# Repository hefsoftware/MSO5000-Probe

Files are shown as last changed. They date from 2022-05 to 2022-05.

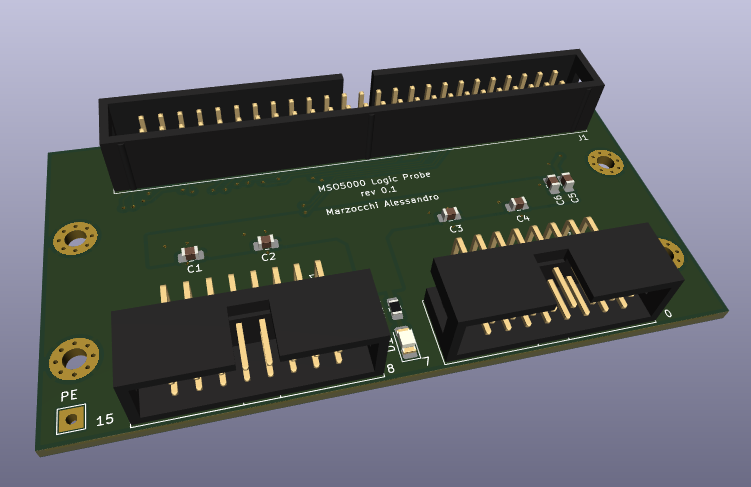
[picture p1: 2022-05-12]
docs/3dView-Top.png

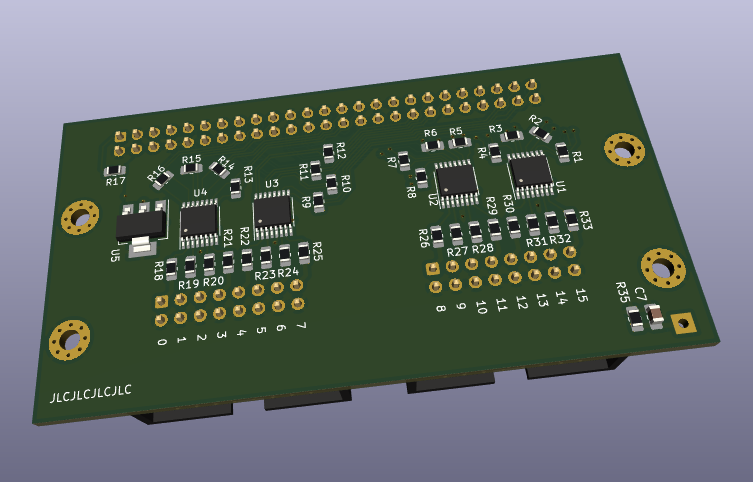
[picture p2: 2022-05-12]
docs/3dView-Bottom.png

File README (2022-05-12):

MSO5000 digital probe. 

The schematic was taken almost verbatim from Faeton's digital-probe-rigol-mso5000 (https://oshwlab.com/f33net/digital-probe-rigol-mso5000).
As their work is acknowledged in the original work a special thank goes to people from EEVblog for pinout of the connector.

Changes from Faeton's:
The schematic and PCB were drawn with Kicad.
The single LVDS buffer SN65LVDS1 was replaced with a 4-line buffer SN65LVDS04. 
Changed linear regulator to MCP1825ST-3302E/DB which has a different pinout from original (available on Digikey)
Inputs order was switched from original (now pin 0 is on the left and pin 15 is on the right) to make routing more "natural" and make the board more compact.

TODO: Add option for switching tab from GND to Vin to make use of original regulator MC33375ST-3.3T3G.

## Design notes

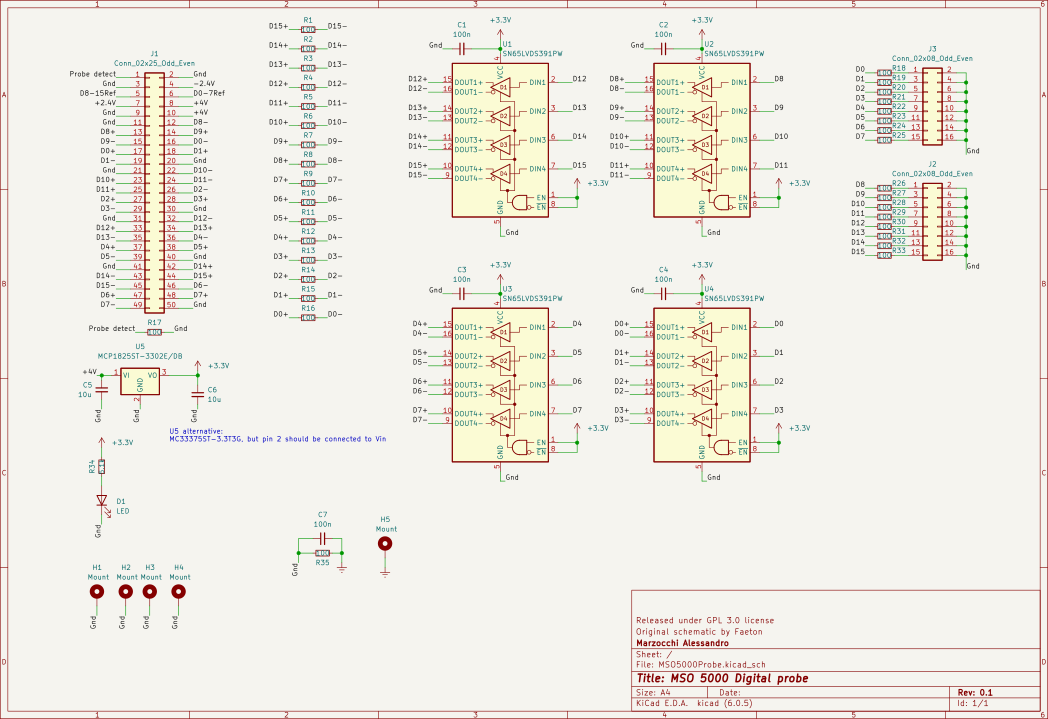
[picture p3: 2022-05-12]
docs/MSO5000Probe.png

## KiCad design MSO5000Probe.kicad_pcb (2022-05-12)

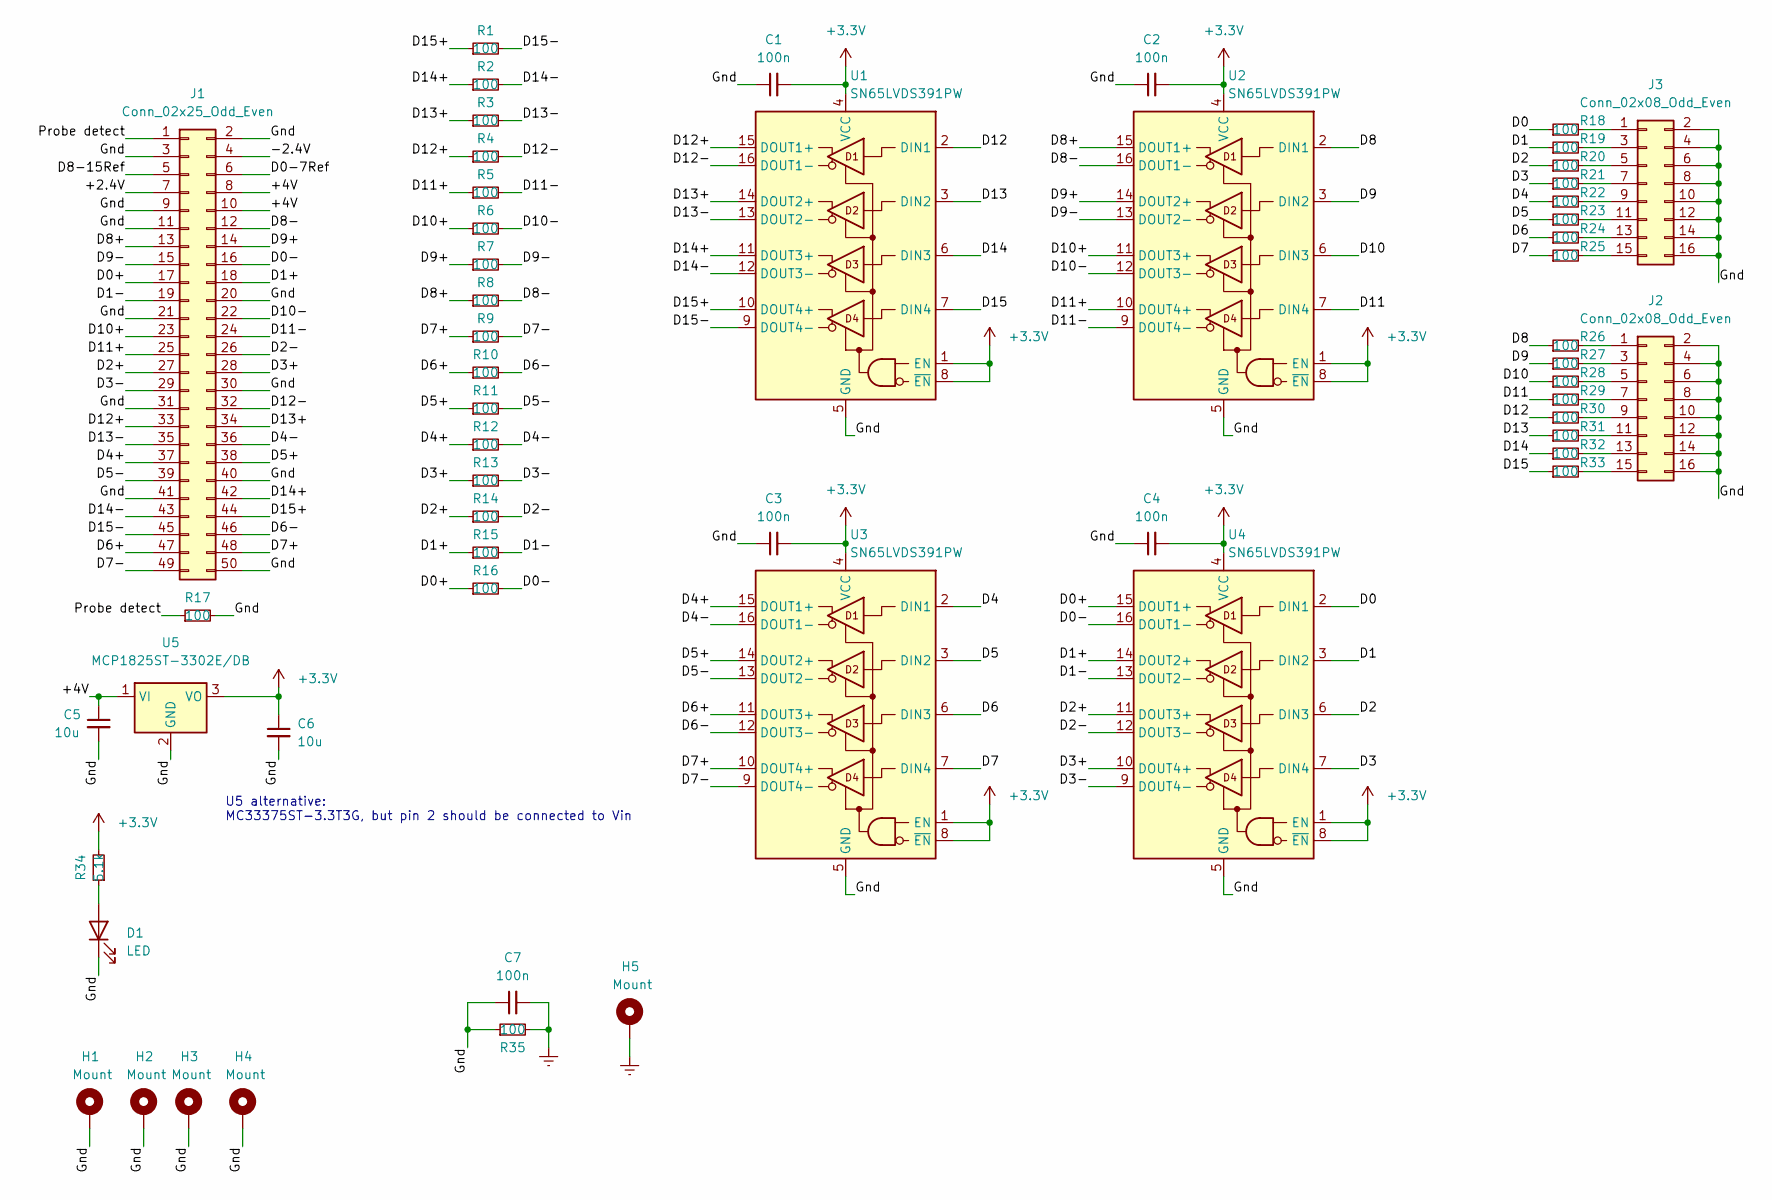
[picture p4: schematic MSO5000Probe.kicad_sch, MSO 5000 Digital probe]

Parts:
C1, C2, C3, C4, C7: 100n; C_0805_2012Metric_Pad1.18x1.45mm_HandSolder
C5, C6: 10u; C_0805_2012Metric_Pad1.18x1.45mm_HandSolder
D1: LED; LED_1206_3216Metric_Pad1.42x1.75mm_HandSolder
H1, H2, H3, H4: Mount; MountingHole_2.7mm_Pad_Via
H5: Mount; TestPoint_THTPad_2.5x2.5mm_Drill1.2mm
J1: Conn_02x25_Odd_Even; IDC-Header_2x25_P2.54mm_Vertical
J2, J3: Conn_02x08_Odd_Even; IDC-Header_2x08_P2.54mm_Horizontal
R1, R2, R3, R4, R5, R6, R7, R8, R9, R10, R11, R12, R13, R14, R15, R16, R17, R18, R19, R20, R21, R22, R23, R24, R25, R26, R27, R28, R29, R30, R31, R32, R33, R35: 100; R_0805_2012Metric_Pad1.20x1.40mm_HandSolder
R34: 5.1k; R_0805_2012Metric_Pad1.20x1.40mm_HandSolder
U1, U2, U3, U4: SN65LVDS391PW; TSSOP-16_4.4x5mm_P0.65mm
U5: MCP1825ST-3302E/DB; SOT-223-3_TabPin2

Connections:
+3V3: C1.2, C2.2, C3.2, C4.2, C6.1, R34.2, U1.1 (EN), U1.4 (VCC), U1.8 (~EN), U2.1 (EN), U2.4 (VCC), U2.8 (~EN), U3.1 (EN), U3.4 (VCC), U3.8 (~EN), U4.1 (EN), U4.4 (VCC), U4.8 (~EN), U5.3 (VO)
/+2.4V: J1.7
/+4V: C5.1, J1.8, J1.10, U5.1 (VI)
/-2.4V: J1.4
/D0: R18.1, U4.2 (DIN1)
/D0+: J1.17, R16.1, U4.15 (DOUT1+)
/D0-: J1.16, R16.2, U4.16 (DOUT1-)
/D0-7Ref: J1.6
/D1: R19.1, U4.3 (DIN2)
/D1+: J1.18, R15.1, U4.14 (DOUT2+)
/D1-: J1.19, R15.2, U4.13 (DOUT2-)
/D2: R20.1, U4.6 (DIN3)
/D2+: J1.27, R14.1, U4.11 (DOUT3+)
/D2-: J1.26, R14.2, U4.12 (DOUT3-)
/D3: R21.1, U4.7 (DIN4)
/D3+: J1.28, R13.1, U4.10 (DOUT4+)
/D3-: J1.29, R13.2, U4.9 (DOUT4-)
/D4: R22.1, U3.2 (DIN1)
/D4+: J1.37, R12.1, U3.15 (DOUT1+)
/D4-: J1.36, R12.2, U3.16 (DOUT1-)
/D5: R23.1, U3.3 (DIN2)
/D5+: J1.38, R11.1, U3.14 (DOUT2+)
/D5-: J1.39, R11.2, U3.13 (DOUT2-)
/D6: R24.1, U3.6 (DIN3)
/D6+: J1.47, R10.1, U3.11 (DOUT3+)
/D6-: J1.46, R10.2, U3.12 (DOUT3-)
/D7: R25.1, U3.7 (DIN4)
/D7+: J1.48, R9.1, U3.10 (DOUT4+)
/D7-: J1.49, R9.2, U3.9 (DOUT4-)
/D8: R26.1, U2.2 (DIN1)
/D8+: J1.13, R8.1, U2.15 (DOUT1+)
/D8-: J1.12, R8.2, U2.16 (DOUT1-)
/D8-15Ref: J1.5
/D9: R27.1, U2.3 (DIN2)
/D9+: J1.14, R7.1, U2.14 (DOUT2+)
/D9-: J1.15, R7.2, U2.13 (DOUT2-)
/D10: R28.1, U2.6 (DIN3)
/D10+: J1.23, R6.1, U2.11 (DOUT3+)
/D10-: J1.22, R6.2, U2.12 (DOUT3-)
/D11: R29.1, U2.7 (DIN4)
/D11+: J1.25, R5.1, U2.10 (DOUT4+)
/D11-: J1.24, R5.2, U2.9 (DOUT4-)
/D12: R30.1, U1.2 (DIN1)
/D12+: J1.33, R4.1, U1.15 (DOUT1+)
/D12-: J1.32, R4.2, U1.16 (DOUT1-)
/D13: R31.1, U1.3 (DIN2)
/D13+: J1.34, R3.1, U1.14 (DOUT2+)
/D13-: J1.35, R3.2, U1.13 (DOUT2-)
/D14: R32.1, U1.6 (DIN3)
/D14+: J1.42, R2.1, U1.11 (DOUT3+)
/D14-: J1.43, R2.2, U1.12 (DOUT3-)
/D15: R33.1, U1.7 (DIN4)
/D15+: J1.44, R1.1, U1.10 (DOUT4+)
/D15-: J1.45, R1.2, U1.9 (DOUT4-)
/Gnd: C1.1, C2.1, C3.1, C4.1, C5.2, C6.2, C7.1, D1.1 (K), H1.1, H2.1, H3.1, H4.1, J1.2, J1.3, J1.9, J1.11, J1.20, J1.21, J1.30, J1.31, J1.40, J1.41, J1.50, J2.2, J2.4, J2.6, J2.8, J2.10, J2.12, J2.14, J2.16, J3.2, J3.4, J3.6, J3.8, J3.10, J3.12, J3.14, J3.16, R17.2, R35.1, U1.5 (GND), U2.5 (GND), U3.5 (GND), U4.5 (GND), U5.2 (GND)
/Probe detect: J1.1, R17.1
Earth: C7.2, H5.1, R35.2
unnamed: D1.2 (A), R34.1
unnamed: J2.1, R26.2
unnamed: J2.3, R27.2
unnamed: J2.5, R28.2
unnamed: J2.7, R29.2
unnamed: J2.9, R30.2
unnamed: J2.11, R31.2
unnamed: J2.13, R32.2
unnamed: J2.15, R33.2
unnamed: J3.1, R18.2
unnamed: J3.3, R19.2
unnamed: J3.5, R20.2
unnamed: J3.7, R21.2
unnamed: J3.9, R22.2
unnamed: J3.11, R23.2
unnamed: J3.13, R24.2
unnamed: J3.15, R25.2

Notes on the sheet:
U5 alternative: MC33375ST-3.3T3G, but pin 2 should be connected to Vin

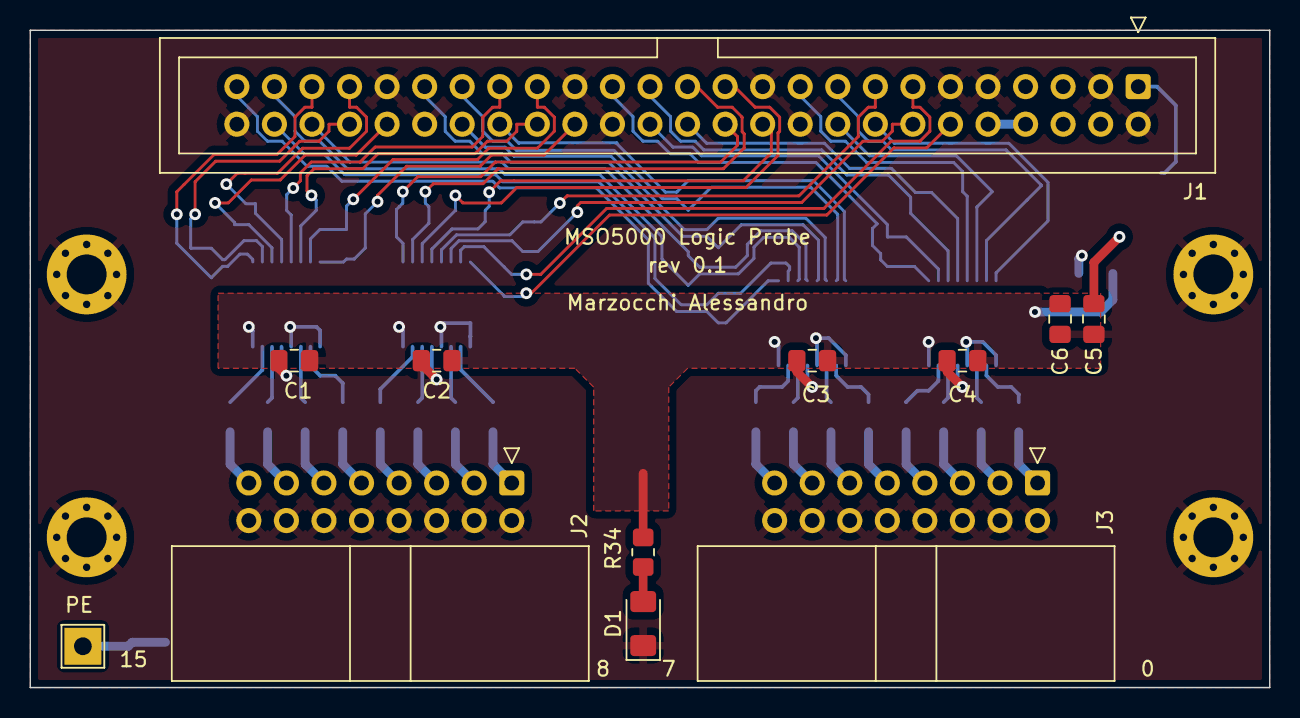
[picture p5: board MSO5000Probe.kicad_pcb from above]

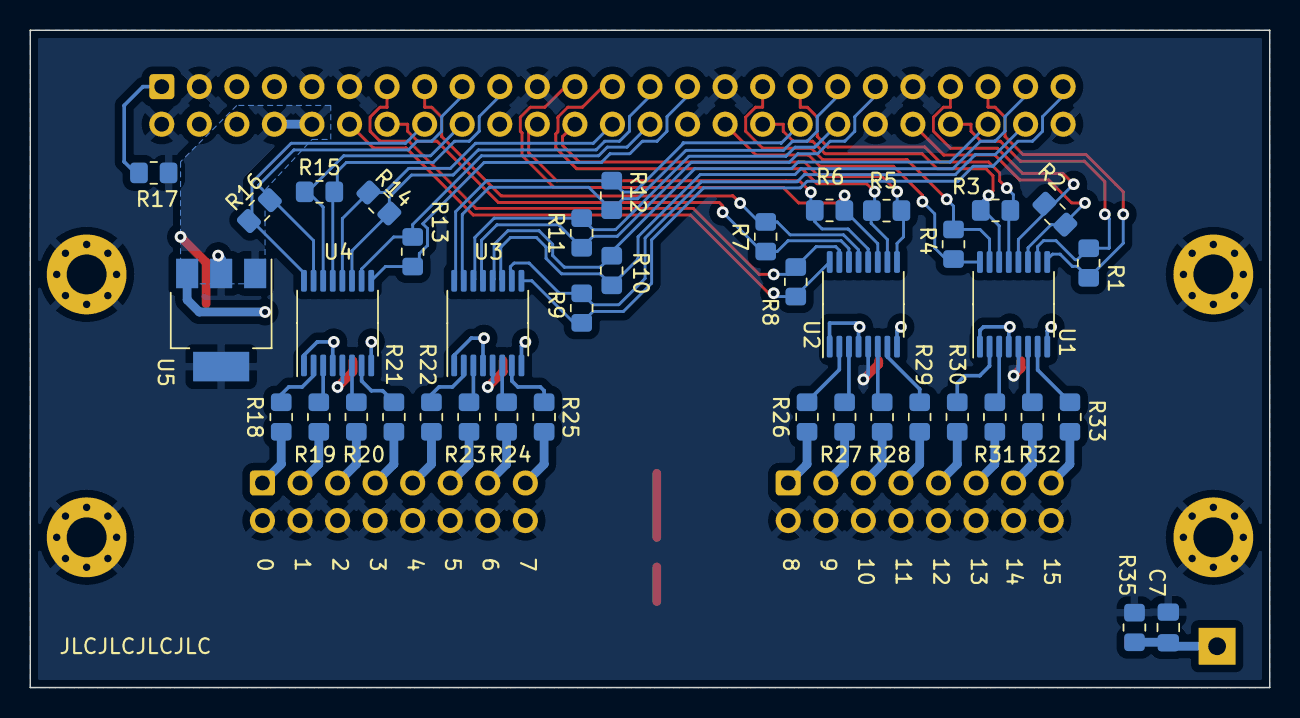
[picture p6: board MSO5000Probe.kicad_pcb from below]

Board: 2 copper layers, 83.8 x 44.4 mm, 56 parts (40 on the bottom side), 70 nets.

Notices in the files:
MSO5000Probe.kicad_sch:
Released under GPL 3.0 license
